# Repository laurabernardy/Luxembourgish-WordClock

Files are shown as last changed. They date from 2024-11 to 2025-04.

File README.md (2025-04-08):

# Lëtzebuergesch Wuertauer - Luxembourgish Word Clock

I taught the excellent [word clock from techniccontroller](https://github.com/techniccontroller/wordclock_esp8266/tree/main) some Luxembourgish.
So this version has a different front plate, grid and an other "start message", as well as the corresponding software changes. The installation process is the same, so I included the authors description in this readme ([down there!](#wordclock-20))

### hardware and its installation

You can find the stl files for the front plate and the letter seperating grid (to avoid light leakage) also in this repo. print it with black PETG (maybe PLA also does the job). Other colors might not keep the light just on one letter.

I followed loosely the [**tutorial**](https://techniccontroller.com/word-clock-with-wifi-and-neopixel/) from techniccontroller when assembling the hardware. 

#### Different and same material 

My wordclock uses 
- as base a 23 cm x 23 cm wooden 3d frame [like this one](https://www.ebay.de/itm/363647167937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)

- diffusion foil (has to be at least frame size) [like this one](https://www.amazon.de/-/en/gp/product/B08R67CGGG/ref=ppx_yo_dt_b_search_asin_title?ie=UTF8&psc=1)

- WS2812B addressable LED stripes 3m, 60 LEDS/m [like this one](https://www.ebay.de/itm/185183965409?var=694400105582)

- and [this](https://www.thingiverse.com/thing:2842012) ESP case on the back

I did not include an on-off-switch in my version and I power it directly from the ESP. If you are unsure with that, you can include the USB socket like in the original tutorial. 
The material, I used same as in the original tutorial were: ESP8266 from AZDelivery, USB power supply 5V/3A,
470 Ohm resistor,
1000uF capacitor,
micro USB cable,
some cables

#### my own assembly

1. I started by 3d printing the Front plate so I could use it, to positionate the LEDs to glue them on the back plate of the frame. For that i used dark eye shadow to trace through the letters on the plate:

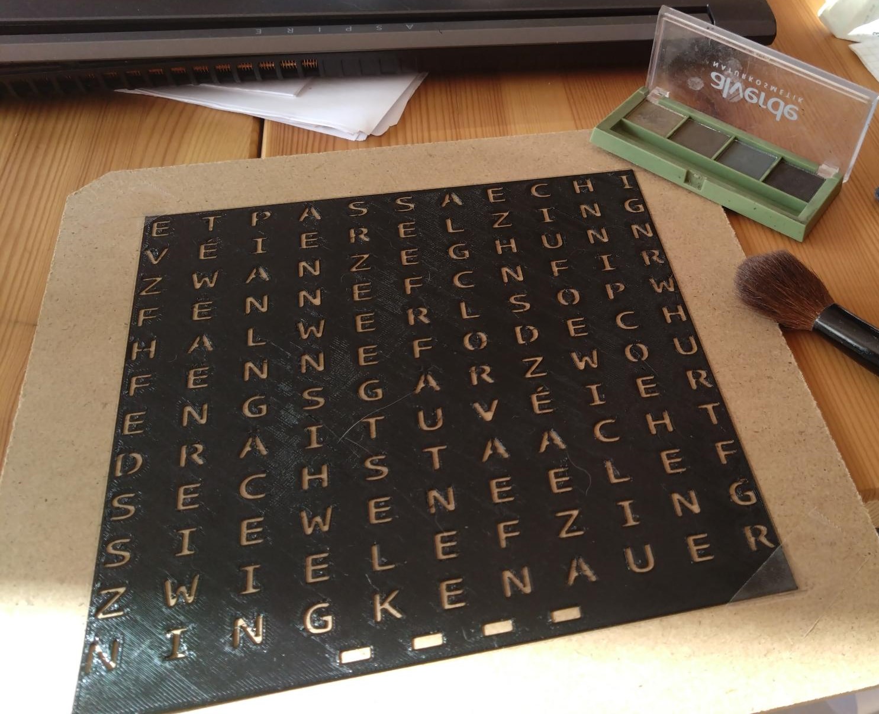
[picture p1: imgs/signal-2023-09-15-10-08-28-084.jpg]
Bild 1
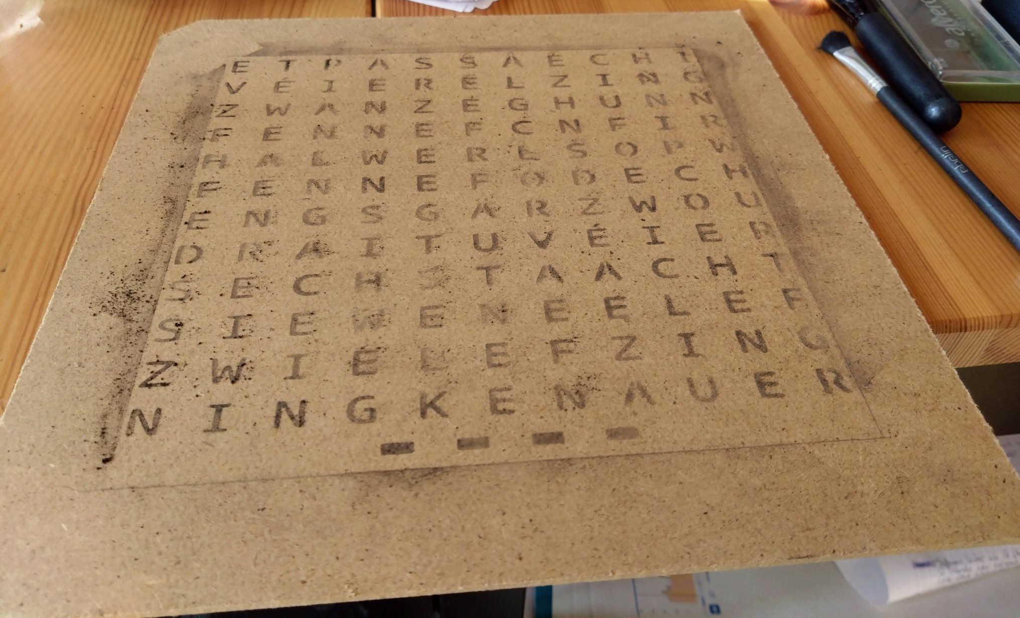
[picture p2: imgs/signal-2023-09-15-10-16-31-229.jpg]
Bild 2
   

3. Then I glued the LEDs strips and connected them following the original tutorial. Keep in mind, that you need 11 LEDs per row and 12 rows (that is different) plus the for LED row at the bottom. 
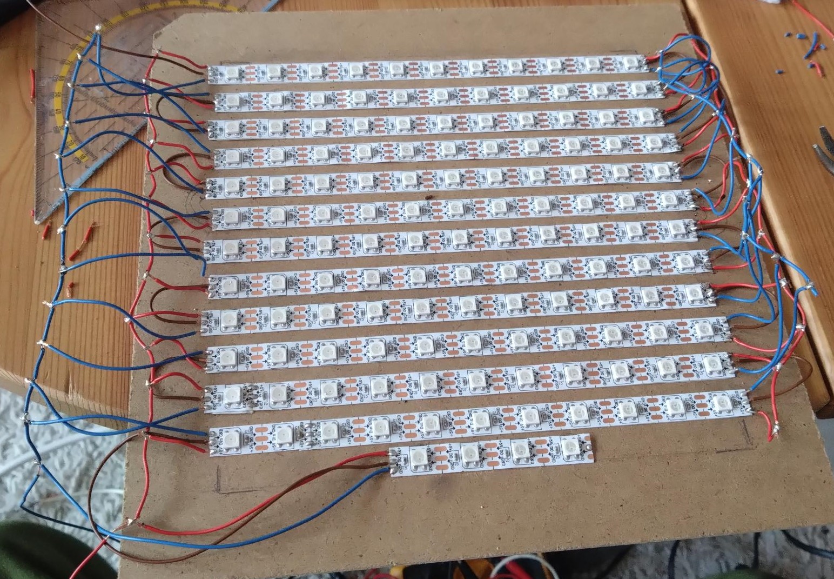
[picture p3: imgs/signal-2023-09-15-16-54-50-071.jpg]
Bild 3
 

4. The connection between the LEDs and to the ESP is also nearly the same as in the original tutorial, I did not include the switch and the additional usb socket. So I connected the LED strips to the VU/5V and the GRD Pin of the ESP.

5. I glued the esp in the printed case from thingiverse at the back of the back plate. 

6. To bring it all together: place the printed grip on the plate, so that every letter is in one of the cells. then you put the diffusor foil on it. Then you put the printed front plate on that. (Ignore the wrong printed grip on top of the image) 
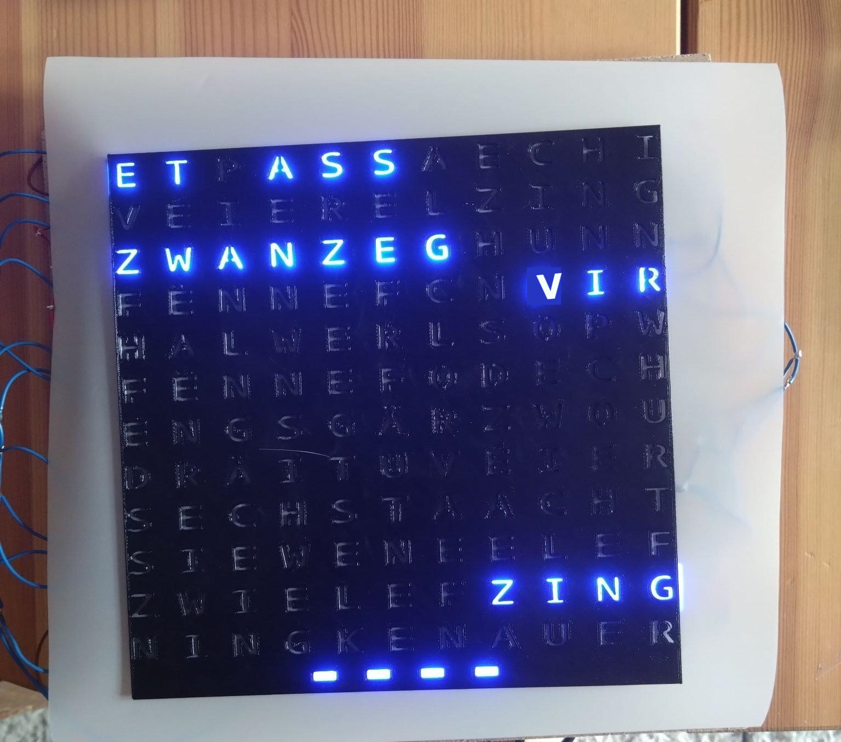
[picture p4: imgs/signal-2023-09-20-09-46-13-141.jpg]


7. You can cut the passepartout of the frame, so it shows all of the letters. Fixate the front plate in the back with some tesa or glue of your gusto. Put it into the frame and - *Taaadaaa* - your Word Clock is ready.

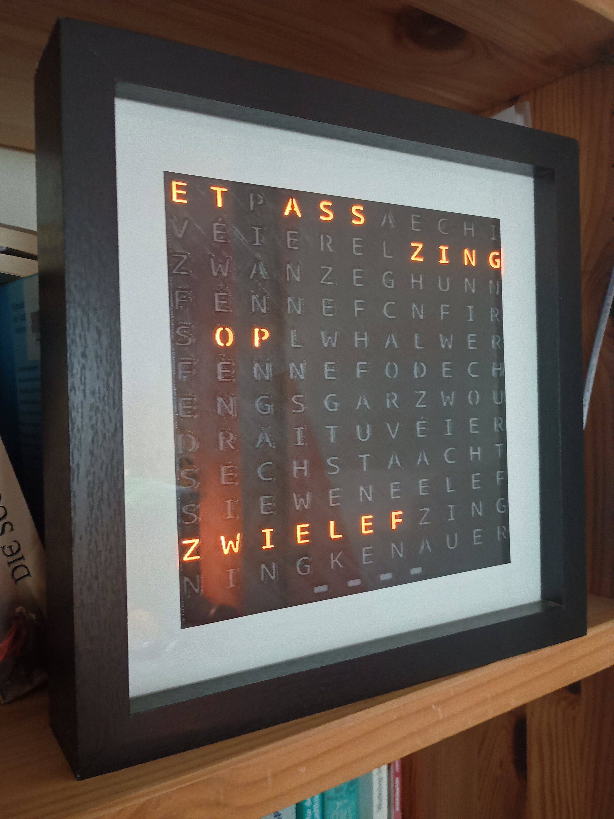
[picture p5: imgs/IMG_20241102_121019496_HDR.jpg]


### small software difference (except the language)

In difference to the original it says "ech hunn dech gär" when starting (it was a present for a beloved one ;-)), you can change that back in wordclock_esp8266.ino, by commenting lines 361 - 379 out and decomment lines 381 - 387. It will show its ip adress instead. 

## Original description from [techniccontroller](https://github.com/techniccontroller/wordclock_esp8266/tree/main)

# Wordclock 2.0

Wordclock 2.0 with ESP8266 and NTP time

More details on my website: https://techniccontroller.com/word-clock-with-wifi-and-neopixel/

**Languages**

The Wordclock is available in **German**, **English** and **Italian** language. By default the language is German. 
To use the English or Italian language please replace the file *wordclockfunctions.ino* with *wordclockfunctions.ino_english* or *wordclockfunctions.ino_italian*.
The code compiles only with one file named *wordclockfunctions.ino*. So please rename the file you want to use to *wordclockfunctions.ino* and replace the existing file.

## Features
- 6 modes (Clock, Digital Clock, SPIRAL animation, TETRIS, SNAKE, PONG)
- time update via NTP server
- automatic summer/wintertime change
- easy WIFI setup with WifiManager
- configurable color
- configurable night mode (start and end time)
- configurable brightness
- automatic mode change
- webserver interface for configuration and control
- physical button to change mode or enable night mode without webserver
- automatic current limiting of LEDs

## Pictures of clock
modes_images2

## Screenshots of webserver UI
screenshots_UI

## Quickstart

1. Clone the project into the sketch folder of the Arduino IDE, 
2. Rename the file "example_secrets.h" to "secrets.h". You don't need to change anything in the file if you want to use the normal WiFi setup with WiFiManager (see section "Remark about the WiFi setup").
3. Install the additional libraries and upload the program to the ESP8266 as usual (See section [*Upload program to ESP8266*](https://github.com/techniccontroller/wordclock_esp8266/blob/main/README.md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) below). 
4. The implemented WiFiManager helps you to set up a WiFi connection with your home WiFi -> on the first startup it will create a WiFi access point named "WordclockAP". Connect your phone to this access point and follow the steps which will be shown to you. 
5. After a successful WiFi setup, open the browser and enter the IP address of your ESP8266 to access the interface of the webserver. 
6. Here you can upload all files located in the folder "data". Please make sure all icons stay in the folder "icons" also on the webserver.

  

## Install needed Libraries

Please download all these libraries as ZIP from GitHub, and extract them in the *libraries* folder of your Sketchbook location (see **File -> Preferences**):

- https://github.com/adafruit/Adafruit-GFX-Library
- https://github.com/adafruit/Adafruit_NeoMatrix
- https://github.com/adafruit/Adafruit_NeoPixel
- https://github.com/tzapu/WiFiManager
- https://github.com/adafruit/Adafruit_BusIO

folder structure should look like this:

```
MySketchbookLocation 
│
└───libraries
│   └───Adafruit-GFX-Library
│   └───Adafruit_NeoMatrix
│   └───Adafruit_NeoPixel
│   └───WiFiManager
│   └───Adafruit_BusIO
│   
└───wordclock_esp8266
    │   wordclock_esp8266.ino
    │   (...)
    |
    └───data
        │   index.html
        |   (...)
        |
        └───icons 
```

## Upload program to ESP8266 with Arduino IDE

#### STEP1: Installation of Arduino IDE
First, the latest version of the Arduino IDE needs to be downloaded and installed from here.

#### STEP2: Installation of ESP8266 Arduino Core
To program the ESP8266 with the Arduino IDE, you need to install the board information first in Arduino IDE. To do that follow the following instructions:

- Start Arduino and open the File -> Preferences window.

- Enter http://arduino.esp8266.com/stable/package_esp8266com_index.json into the Additional Board Manager URLs field. You can add multiple URLs, separating them with commas.


- Open Boards Manager from Tools > Board menu and search for "esp8266".

- Click the install button.

- Don’t forget to select your ESP8266 board from Tools > Board menu after installation (e.g NodeMCU 1.0)


#### STEP3: Upload a program to ESP8266

- Open wordclock_esp8266.ino in Arduino IDE
- Connect ESP8266 board with Computer
- Select right serial Port in Tools -> Port
- Click on the upload button in the Arduino IDE to upload the program to the ESP8266 Module.     


## Remark about the WiFi setup

Regarding the WiFi setting, I have actually implemented two variants: 
1. By default the WifiManager is activated. That is, the word clock makes the first time its own WiFi (should be called "WordclockAP"). There you connect from a cell phone to `192.168.4.1`* and you can perform the configuration of the WiFi settings conveniently as with a SmartHome devices (Very elegant 😊)
2. Another (traditional) variant is to define the wifi credentials in the code (in secrets.h). 
    - For this you have to comment out lines 230 to 251 in the code of the file *wordclock_esp8266.ino* (add /\* before and \*/ after) 
    - and comment out lines 257 to 305 (remove /\* and \*/)
(* default IP provided by the WifiMAnager library.)

## Resetting the WiFi configuration

You can clear the stored WiFi credentials and restart the WiFi setup described above with these steps:
1. Open the settings panel in the web UI.
2. Enable 'Reset WiFi' slider.
3. Save settings.
4. LED test should be performed.
5. Disconnect and reconnect the power. WiFi credentials were removed. The setup should be restarted.
Resetting the wifi credentials does not delete uploaded files.

## Remark about Logging

The wordclock sends continuous log messages to the serial port and via multicast UDP. If you want to see these messages, you have to 

- open the serial monitor in the Arduino IDE (Tools -> Serial Monitor). The serial monitor must be set to 115200 baud.

OR

- run the following steps for the multicast UDP logging:

1. Starting situation: wordclock is connected to WLAN, a computer with installed Python (https://www.python.org/downloads/) is in the same local area network (WLAN or LAN doesn't matter).
3. Open the file **multicastUDP_receiver.py** in a text editor and in line 81 enter the IP address of the computer (not the wordclock!).
```python	
# ip address of network interface
MCAST_IF_IP = '192.168.0.7'
```
4. Execute the script with following command: 

```bash
python multicastUDP_receiver_analyzer.py
```

5. Now you should see the log messages of the word clock (every 5 seconds a heartbeat message and the currently displayed time). 
If this is not the case, there could be a problem with the network settings of the computer, then recording is unfortunately not possible.

6. If special events (failed NTP update, reboot) occur, a section of the log is saved in a file called *log.txt*. 
In principle, the events are not critical and will occur from time to time, but should not be too frequent.

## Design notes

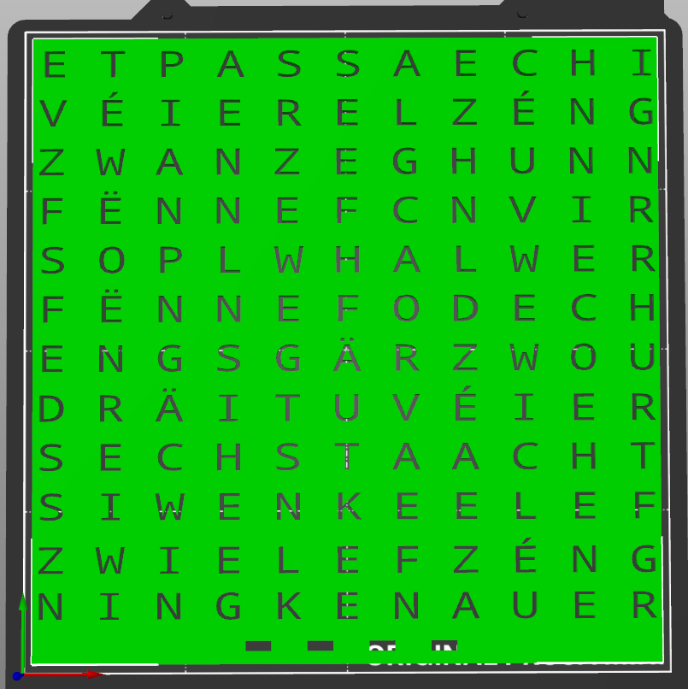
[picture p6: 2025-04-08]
grid/corrected_frontplate.png

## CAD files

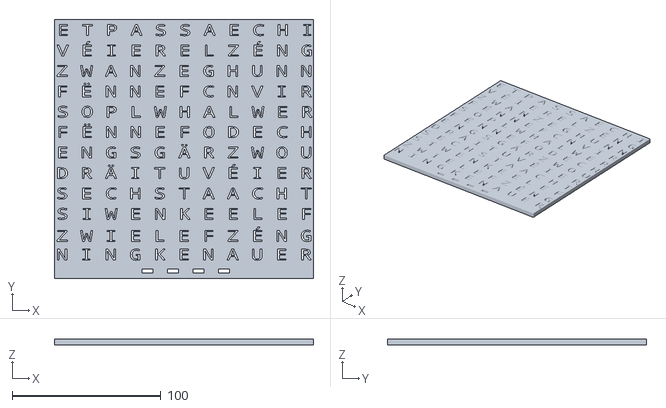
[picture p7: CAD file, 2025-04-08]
grid/corrected_wuertauer.stl
174.4 x 174.4 x 4.00

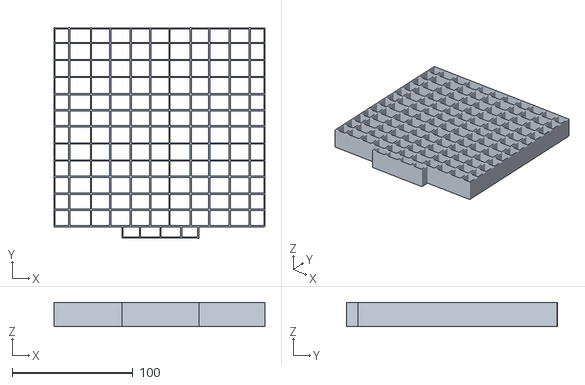
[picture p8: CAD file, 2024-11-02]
grid/Grid.stl
174.8 x 174.4 x 20.0

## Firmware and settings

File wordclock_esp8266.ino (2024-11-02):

/**
 * Wordclock 2.0 - Wordclock with ESP8266 and NTP time update
 * 
 * created by techniccontroller 04.12.2021
 * 
 * components:
 * - ESP8266
 * - Neopixelstrip
 * 
 * Board settings:
 * - Board: NodeMCU 1.0 (ESP-12E Module)
 * - Flash Size: 4MB (FS:2MB OTA:~1019KB)
 * - Upload Speed: 115200
 *  
 * 
 * with code parts from:
 * - Adafruit NeoPixel strandtest.ino, https://github.com/adafruit/Adafruit_NeoPixel/blob/master/examples/strandtest/strandtest.ino
 * - Esp8266 und Esp32 webserver https://fipsok.de/
 * - https://github.com/pmerlin/PMR-LED-Table/blob/master/tetrisGame.ino
 * - https://randomnerdtutorials.com/wifimanager-with-esp8266-autoconnect-custom-parameter-and-manage-your-ssid-and-password/ 
 * 
 */

#include "secrets.h"                    // rename the file example_secrets.h to secrets.h after cloning the project. More information in README.md
#include <LittleFS.h>
#include <Adafruit_GFX.h>               // https://github.com/adafruit/Adafruit-GFX-Library
#include <Adafruit_NeoMatrix.h>         // https://github.com/adafruit/Adafruit_NeoMatrix
#include <Adafruit_NeoPixel.h>          // NeoPixel library used to run the NeoPixel LEDs: https://github.com/adafruit/Adafruit_NeoPixel
#include <ESP8266WiFi.h>
#include <WiFiUdp.h>
#include <ArduinoOTA.h>
#include <ESP8266WebServer.h>
#include "Base64.h"                    // copied from https://github.com/Xander-Electronics/Base64 
#include <DNSServer.h>
#include <WiFiManager.h>                //https://github.com/tzapu/WiFiManager WiFi Configuration Magic
#include <EEPROM.h>                     //from ESP8266 Arduino Core (automatically installed when ESP8266 was installed via Boardmanager)

// own libraries
#include "udplogger.h"
#include "ntp_client_plus.h"
#include "ledmatrix.h"
#include "tetris.h"
#include "snake.h"
#include "pong.h"


// ----------------------------------------------------------------------------------
//                                        CONSTANTS
// ----------------------------------------------------------------------------------

#define EEPROM_SIZE 30      // size of EEPROM to save persistent variables
#define ADR_NM_START_H 0
#define ADR_NM_END_H 4
#define ADR_NM_START_M 8
#define ADR_NM_END_M 12
#define ADR_BRIGHTNESS 16
#define ADR_MC_RED 20
#define ADR_MC_GREEN 22
#define ADR_MC_BLUE 24


#define NEOPIXELPIN 5       // pin to which the NeoPixels are attached
#define NUMPIXELS 125       // number of pixels attached to Attiny85
#define BUTTONPIN 14        // pin to which the button is attached
#define LEFT 1
#define RIGHT 2
#define LINE 10
#define RECT 5

#define PERIOD_HEARTBEAT 1000
#define PERIOD_ANIMATION 200
#define PERIOD_TETRIS 50
#define PERIOD_SNAKE 50
#define PERIOD_PONG 10
#define TIMEOUT_LEDDIRECT 5000
#define PERIOD_STATECHANGE 10000
#define PERIOD_NTPUPDATE 30000
#define PERIOD_TIMEVISUUPDATE 1000
#define PERIOD_MATRIXUPDATE 100
#define PERIOD_NIGHTMODECHECK 20000

#define SHORTPRESS 100
#define LONGPRESS 2000

#define CURRENT_LIMIT_LED 2500 // limit the total current sonsumed by LEDs (mA)

#define DEFAULT_SMOOTHING_FACTOR 0.5

// number of colors in colors array
#define NUM_COLORS 7

// own datatype for matrix movement (snake and spiral)
enum direction {right, left, up, down};

// width of the led matrix
#define WIDTH 11
// height of the led matrix
#define HEIGHT 12

// own datatype for state machine states
#define NUM_STATES 6
enum ClockState {st_clock, st_diclock, st_spiral, st_tetris, st_snake, st_pingpong};
const String stateNames[] = {"Clock", "DiClock", "Sprial", "Tetris", "Snake", "PingPong"};
// PERIODS for each state (different for stateAutoChange or Manual mode)
const uint16_t PERIODS[2][NUM_STATES] = { { PERIOD_TIMEVISUUPDATE, // stateAutoChange = 0
                                            PERIOD_TIMEVISUUPDATE, 
                                            PERIOD_ANIMATION,
                                            PERIOD_TETRIS, 
                                            PERIOD_SNAKE,  
                                            PERIOD_PONG},
                                          { PERIOD_TIMEVISUUPDATE, // stateAutoChange = 1
                                            PERIOD_TIMEVISUUPDATE, 
                                            PERIOD_ANIMATION,
                                            PERIOD_ANIMATION, 
                                            PERIOD_ANIMATION,  
                                            PERIOD_PONG}};

// ports
const unsigned int localPort = 2390;
const unsigned int HTTPPort = 80;
const unsigned int logMulticastPort = 8123;
const unsigned int DNSPort = 53;

// ip addresses for multicast logging
IPAddress logMulticastIP = IPAddress(230, 120, 10, 2);

// ip addresses for Access Point
IPAddress IPAdress_AccessPoint(192,168,10,2);
IPAddress Gateway_AccessPoint(192,168,10,0);
IPAddress Subnetmask_AccessPoint(255,255,255,0);

// hostname
const String hostname = "wordclock";

// URL DNS server
const char WebserverURL[] = "www.wordclock.local";

// ----------------------------------------------------------------------------------
//                                        GLOBAL VARIABLES
// ----------------------------------------------------------------------------------

// Webserver
ESP8266WebServer server(HTTPPort);

//DNS Server
DNSServer DnsServer;

// Wifi server. keep around to support resetting.
WiFiManager wifiManager;

// When we setup the NeoPixel library, we tell it how many pixels, and which pin to use to send signals.
// Note that for older NeoPixel strips you might need to change the third parameter--see the strandtest
// example for more information on possible values.
Adafruit_NeoMatrix matrix = Adafruit_NeoMatrix(WIDTH, HEIGHT+1, NEOPIXELPIN,
  NEO_MATRIX_TOP + NEO_MATRIX_LEFT +
  NEO_MATRIX_ROWS + NEO_MATRIX_ZIGZAG,
  NEO_GRB            + NEO_KHZ800);


// seven predefined colors24bit (green, red, yellow, purple, orange, lightgreen, blue) 
const uint32_t colors24bit[NUM_COLORS] = {
  LEDMatrix::Color24bit(0, 255, 0),
  LEDMatrix::Color24bit(255, 0, 0),
  LEDMatrix::Color24bit(200, 200, 0),
  LEDMatrix::Color24bit(255, 0, 200),
  LEDMatrix::Color24bit(255, 128, 0), 
  LEDMatrix::Color24bit(0, 128, 0), 
  LEDMatrix::Color24bit(0, 0, 255) };

uint8_t brightness = 40;            // current brightness of leds
bool sprialDir = false;

// timestamp variables
long lastheartbeat = millis();      // time of last heartbeat sending
long lastStep = millis();           // time of last animation step
long lastLEDdirect = 0;             // time of last direct LED command (=> fall back to normal mode after timeout)
long lastStateChange = millis();    // time of last state change
long lastNTPUpdate = millis() - (PERIOD_NTPUPDATE-5000);  // time of last NTP update
long lastAnimationStep = millis();  // time of last Matrix update
long lastNightmodeCheck = millis(); // time of last nightmode check
long buttonPressStart = 0;          // time of push button press start 

// Create necessary global objects
UDPLogger logger;
WiFiUDP NTPUDP;
NTPClientPlus ntp = NTPClientPlus(NTPUDP, "pool.ntp.org", 1, true);
LEDMatrix ledmatrix = LEDMatrix(&matrix, brightness, &logger);
Tetris mytetris = Tetris(&ledmatrix, &logger);
Snake mysnake = Snake(&ledmatrix, &logger);
Pong mypong = Pong(&ledmatrix, &logger);

float filterFactor = DEFAULT_SMOOTHING_FACTOR;// stores smoothing factor for led transition
uint8_t currentState = st_clock;              // stores current state
bool stateAutoChange = false;                 // stores state of automatic state change
bool nightMode = false;                       // stores state of nightmode
uint32_t maincolor_clock = colors24bit[2];    // color of the clock and digital clock
uint32_t maincolor_snake = colors24bit[1];    // color of the random snake animation
bool apmode = false;                          // stores if WiFi AP mode is active

// nightmode settings
int nightModeStartHour = 22;
int nightModeStartMin = 0;
int nightModeEndHour = 7;
int nightModeEndMin = 0;

// Watchdog counter to trigger restart if NTP update was not possible 30 times in a row (5min)
int watchdogCounter = 30;

// ----------------------------------------------------------------------------------
//                                        SETUP
// ----------------------------------------------------------------------------------

void setup() {
  // put your setup code here, to run once:
  Serial.begin(115200);
  delay(100);
  Serial.println();
  Serial.printf("\nSketchname: %s\nBuild: %s\n", (__FILE__), (__TIMESTAMP__));
  Serial.println();

  //Init EEPROM
  EEPROM.begin(EEPROM_SIZE);

  // Load color for clock from EEPROM
  loadMainColor();

  // configure button pin as input
  pinMode(BUTTONPIN, INPUT_PULLUP);

  // setup Matrix LED functions
  ledmatrix.setupMatrix();
  ledmatrix.setCurrentLimit(CURRENT_LIMIT_LED);

  // Turn on minutes leds (blue)
  ledmatrix.setMinIndicator(15, colors24bit[6]);
  ledmatrix.drawOnMatrixInstant();


  /** Use WiFiMaanger for handling initial Wifi setup **/

  // Local intialization. Once its business is done, there is no need to keep it around


  // Uncomment and run it once, if you want to erase all the stored information
  //wifiManager.resetSettings();

  // set custom ip for portal
  //wifiManager.setAPStaticIPConfig(IPAdress_AccessPoint, Gateway_AccessPoint, Subnetmask_AccessPoint);

  // fetches ssid and pass from eeprom and tries to connect
  // if it does not connect it starts an access point with the specified name
  // here "wordclockAP"
  // and goes into a blocking loop awaiting configuration
  wifiManager.autoConnect(AP_SSID);

  // if you get here you have connected to the WiFi
  Serial.println("Connected.");
  Serial.println("IP address: ");
  Serial.println(WiFi.localIP()); 

  // Turn off minutes leds
  ledmatrix.setMinIndicator(15, 0);
  ledmatrix.drawOnMatrixInstant();

   
  
  /** (alternative) Use directly STA/AP Mode of ESP8266   **/
  
  /* 
  // We start by connecting to a WiFi network
  Serial.print("Connecting to ");
  Serial.println(WIFI_SSID);
  
  // We start by connecting to a WiFi network
  WiFi.mode(WIFI_STA);
  //Set new hostname
  WiFi.hostname(hostname.c_str());
  WiFi.begin(WIFI_SSID, WIFI_PASS);
  //wifi_station_set_hostname("esplamp");

  int timeoutcounter = 0;
  while (WiFi.status() != WL_CONNECTED && timeoutcounter < 30) {
    ledmatrix.setMinIndicator(15, colors24bit[6]);
    ledmatrix.drawOnMatrixInstant();
    delay(250);
    ledmatrix.setMinIndicator(15, 0);
    ledmatrix.drawOnMatrixInstant();
    delay(250);
    Serial.print(".");
    timeoutcounter++;
  }

  // start request of program
  if (WiFi.status() == WL_CONNECTED) {      //Check WiFi connection status
    Serial.println("");

    Serial.println("WiFi connected");
    Serial.println("IP address: ");
    Serial.println(WiFi.localIP()); 
    WiFi.setAutoReconnect(true);
    WiFi.persistent(true);
  
  } else {
    // no wifi found -> open access point
    WiFi.mode(WIFI_AP);
    WiFi.softAPConfig(IPAdress_AccessPoint, Gateway_AccessPoint, Subnetmask_AccessPoint);
    WiFi.softAP(AP_SSID, AP_PASS);
    apmode = true;

    // start DNS Server
    DnsServer.setTTL(300);
    DnsServer.start(DNSPort, WebserverURL, IPAdress_AccessPoint);

    IPAddress myIP = WiFi.softAPIP();
    Serial.print("AP IP address: ");
    Serial.println(myIP);
  }*/

  // init ESP8266 File manager (LittleFS)
  setupFS();

  // setup OTA
  setupOTA(hostname);

  server.on("/cmd", handleCommand); // process commands
  server.on("/data", handleDataRequest); // process datarequests
  server.on("/leddirect", HTTP_POST, handleLEDDirect); // Call the 'handleLEDDirect' function when a POST request is made to URI "/leddirect"
  server.begin();
  
  // create UDP Logger to send logging messages via UDP multicast
  logger = UDPLogger(WiFi.localIP(), logMulticastIP, logMulticastPort);
  logger.setName("Wordclock 2.0");
  logger.logString("Start program\n");
  delay(10);
  logger.logString("Sketchname: "+ String(__FILE__));
  delay(10);
  logger.logString("Build: " + String(__TIMESTAMP__));
  delay(10);
  logger.logString("IP: " + WiFi.localIP().toString());
  delay(10);
  logger.logString("Reset Reason: " + ESP.getResetReason());

  if(!ESP.getResetReason().equals("Software/System restart")){
    // test quickly each LED
    for(int r = 0; r < HEIGHT; r++){
        for(int c = 0; c < WIDTH; c++){
        matrix.fillScreen(0);
        matrix.drawPixel(c, r, LEDMatrix::color24to16bit(colors24bit[2]));
        matrix.show();
        delay(10); 
        }
    }
    
    // clear Matrix
    matrix.fillScreen(0);
    matrix.show();
    delay(200);

    // display IP
    uint8_t address = WiFi.localIP()[3];
    matrix.drawPixel(7, 0, LEDMatrix::color24to16bit(colors24bit[4]));
    matrix.drawPixel(8, 0, LEDMatrix::color24to16bit(colors24bit[4]));
    matrix.drawPixel(9, 0, LEDMatrix::color24to16bit(colors24bit[4]));
    matrix.drawPixel(7, 2, LEDMatrix::color24to16bit(colors24bit[4]));
    matrix.drawPixel(8, 2, LEDMatrix::color24to16bit(colors24bit[4]));
    matrix.drawPixel(9, 2, LEDMatrix::color24to16bit(colors24bit[4]));
    matrix.drawPixel(10, 2, LEDMatrix::color24to16bit(colors24bit[4]));
    matrix.drawPixel(7, 5, LEDMatrix::color24to16bit(colors24bit[4]));
    matrix.drawPixel(8, 5, LEDMatrix::color24to16bit(colors24bit[4]));
    matrix.drawPixel(9, 5, LEDMatrix::color24to16bit(colors24bit[4]));
    matrix.drawPixel(10, 5, LEDMatrix::color24to16bit(colors24bit[4]));
    matrix.drawPixel(4, 6, LEDMatrix::color24to16bit(colors24bit[4]));
    matrix.drawPixel(5, 6, LEDMatrix::color24to16bit(colors24bit[4]));
    matrix.drawPixel(6, 6, LEDMatrix::color24to16bit(colors24bit[4]));
    matrix.show();
    delay(8000);
    matrix.fillScreen(0);
    matrix.show();
    delay(200);

    //ledmatrix.printChar(1, 0, 'I', maincolor_clock);
    //ledmatrix.printChar(5, 0, 'P', maincolor_clock);
    //ledmatrix.printNumber(0, 6, (address/100), maincolor_clock);
    //ledmatrix.printNumber(4, 6, (address/10)%10, maincolor_clock);
    //ledmatrix.printNumber(8, 6, address%10, maincolor_clock);
    //ledmatrix.drawOnMatrixInstant();
    //delay(2000);


    // clear matrix
    ledmatrix.gridFlush();
    ledmatrix.drawOnMatrixInstant();
  }

  // setup NTP
  ntp.setupNTPClient();
  logger.logString("NTP running");
  logger.logString("Time: " +  ntp.getFormattedTime());
  logger.logString("TimeOffset (seconds): " + String(ntp.getTimeOffset()));

  // show the current time for short time in words
  int hours = ntp.getHours24();
  int minutes = ntp.getMinutes();
  String timeMessage = timeToString(hours, minutes);
  showStringOnClock(timeMessage, maincolor_clock);
  drawMinuteIndicator(minutes, maincolor_clock);
  ledmatrix.drawOnMatrixSmooth(filterFactor);


  // init all animation modes
  // init snake
  randomsnake(true, 8, colors24bit[1], -1);
  // init spiral
  spiral(true, sprialDir, WIDTH-6);
  // init random tetris
  randomtetris(true);

  // Read nightmode setting from EEPROM
  nightModeStartHour = readIntEEPROM(ADR_NM_START_H);
  nightModeStartMin = readIntEEPROM(ADR_NM_START_M);
  nightModeEndHour = readIntEEPROM(ADR_NM_END_H);
  nightModeEndMin = readIntEEPROM(ADR_NM_END_M);
  if(nightModeStartHour < 0 || nightModeStartHour > 23) nightModeStartHour = 22;
  if(nightModeStartMin < 0 || nightModeStartMin > 59) nightModeStartMin = 0;
  if(nightModeEndHour < 0 || nightModeEndHour > 23) nightModeEndHour = 7;
  if(nightModeEndMin < 0 || nightModeEndMin > 59) nightModeEndMin = 0;
  logger.logString("Nightmode starts at: " + String(nightModeStartHour) + ":" + String(nightModeStartMin));
  logger.logString("Nightmode ends at: " + String(nightModeEndHour) + ":" + String(nightModeEndMin));

  // Read brightness setting from EEPROM, lower limit is 10 so that the LEDs are not completely off
  brightness = readIntEEPROM(ADR_BRIGHTNESS);
  if(brightness < 10) brightness = 10;
  logger.logString("Brightness: " + String(brightness));
  ledmatrix.setBrightness(brightness);
  
}


// ----------------------------------------------------------------------------------
//                                        LOOP
// ----------------------------------------------------------------------------------

void loop() {
  // handle OTA
  handleOTA();
  
  // handle Webserver
  server.handleClient();

  // send regularly heartbeat messages via UDP multicast
  if(millis() - lastheartbeat > PERIOD_HEARTBEAT){
    logger.logString("Heartbeat, state: " + stateNames[currentState] + ", FreeHeap: " + ESP.getFreeHeap() + ", HeapFrag: " + ESP.getHeapFragmentation() + ", MaxFreeBlock: " + ESP.getMaxFreeBlockSize() + "\n");
    lastheartbeat = millis();

    // Check wifi status (only if no apmode)
    if(!apmode && WiFi.status() != WL_CONNECTED){
      Serial.println("connection lost");
      ledmatrix.gridAddPixel(0, 5, colors24bit[1]);
      ledmatrix.drawOnMatrixInstant();
    }
  }

  // handle mode behaviours (trigger loopCycles of different modes depending on current mode)
  if(!nightMode && (millis() - lastStep > PERIODS[stateAutoChange][currentState]) && (millis() - lastLEDdirect > TIMEOUT_LEDDIRECT)){
    switch(currentState){
      // state clock
      case st_clock:
        {
          int hours = ntp.getHours24();
          int minutes = ntp.getMinutes();
          showStringOnClock(timeToString(hours, minutes), maincolor_clock);
          drawMinuteIndicator(minutes, maincolor_clock);
        }
        break;
      // state diclock
      case st_diclock:
        {
          int hours = ntp.getHours24();
          int minutes = ntp.getMinutes();
          showDigitalClock(hours, minutes, maincolor_clock);
        }
        break;
      // state spiral
      case st_spiral:
        {
          int res = spiral(false, sprialDir, WIDTH-6);
          if(res && sprialDir == 0){
            // change spiral direction to closing (draw empty leds)
            sprialDir = 1;
            // init spiral with new spiral direction
            spiral(true, sprialDir, WIDTH-6);
            
          }else if(res && sprialDir == 1){
            // reset spiral direction to normal drawing leds
            sprialDir = 0;
            // init spiral with new spiral direction
            spiral(true, sprialDir, WIDTH-6);
          }
        }
        break;
      // state tetris
      case st_tetris:
        {
          if(stateAutoChange){
            randomtetris(false);
          }
          else{
            mytetris.loopCycle();
          }
        }
        break;
      // state snake
      case st_snake:
        {
          if(stateAutoChange){
            ledmatrix.gridFlush();
            int res = randomsnake(false, 8, maincolor_snake, -1);
            if(res){
              // init snake for next run
              randomsnake(true, 8, maincolor_snake, -1);
            }
          }
          else{
            mysnake.loopCycle();
          }
        }
        break;
      // state pingpong
      case st_pingpong:
        {
          mypong.loopCycle();
        }
        break;
    }    
    
    lastStep = millis();
  }

  // periodically write colors to matrix
  if(millis() - lastAnimationStep > PERIOD_MATRIXUPDATE){
    ledmatrix.drawOnMatrixSmooth(filterFactor);
    lastAnimationStep = millis();
  }

  // handle button press
  handleButton();

  // handle state changes
  if(stateAutoChange && (millis() - lastStateChange > PERIOD_STATECHANGE) && !nightMode){
    // increment state variable and trigger state change
    stateChange((currentState + 1) % NUM_STATES);
    
    // save last automatic state change
    lastStateChange = millis();
  }

  // NTP time update
  if(millis() - lastNTPUpdate > PERIOD_NTPUPDATE){
    int res = ntp.updateNTP();
    if(res == 0){
      ntp.calcDate();
      logger.logString("NTP-Update successful");
      logger.logString("Time: " +  ntp.getFormattedTime());
      logger.logString("Date: " +  ntp.getFormattedDate());
      logger.logString("Day of Week (Mon=1, Sun=7): " +  String(ntp.getDayOfWeek()));
      logger.logString("TimeOffset (seconds): " + String(ntp.getTimeOffset()));
      logger.logString("Summertime: " + String(ntp.updateSWChange()));
      lastNTPUpdate = millis();
      watchdogCounter = 30;
    }
    else if(res == -1){
      logger.logString("NTP-Update not successful. Reason: Timeout");
      lastNTPUpdate += 10000;
      watchdogCounter--;
    }
    else if(res == 1){
      logger.logString("NTP-Update not successful. Reason: Too large time difference");
      logger.logString("Time: " +  ntp.getFormattedTime());
      logger.logString("Date: " +  ntp.getFormattedDate());
      logger.logString("Day of Week (Mon=1, Sun=7): " +  ntp.getDayOfWeek());
      logger.logString("TimeOffset (seconds): " + String(ntp.getTimeOffset()));
      logger.logString("Summertime: " + String(ntp.updateSWChange()));
      lastNTPUpdate += 10000;
      watchdogCounter--;
    }
    else {
      logger.logString("NTP-Update not successful. Reason: NTP time not valid (<1970)");
      lastNTPUpdate += 10000;
      watchdogCounter--;
    }

    logger.logString("Watchdog Counter: " + String(watchdogCounter));
    if(watchdogCounter <= 0){
        logger.logString("Trigger restart due to watchdog...");
        delay(100);
        ESP.restart();
    }
    
  }

  // check if nightmode need to be activated
  if(millis() - lastNightmodeCheck > PERIOD_NIGHTMODECHECK){
    int hours = ntp.getHours24();
    int minutes = ntp.getMinutes();
    
    if(hours == nightModeStartHour && minutes == nightModeStartMin){
      setNightmode(true);
    }
    else if(hours == nightModeEndHour && minutes == nightModeEndMin){
      setNightmode(false);
    }
    
    lastNightmodeCheck = millis();
  }
 
}


// ----------------------------------------------------------------------------------
//                                        OTHER FUNCTIONS
// ----------------------------------------------------------------------------------
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

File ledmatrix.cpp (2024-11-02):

#include "ledmatrix.h"
#include "own_font.h"

/**
 * @brief Construct a new LEDMatrix::LEDMatrix object
 * 
 * @param mymatrix pointer to Adafruit_NeoMatrix object
 * @param mybrightness the initial brightness of the leds
 * @param mylogger pointer to the UDPLogger object
 */
LEDMatrix::LEDMatrix(Adafruit_NeoMatrix *mymatrix, uint8_t mybrightness, UDPLogger *mylogger){
    neomatrix = mymatrix;
    brightness = mybrightness;
    logger = mylogger;
    currentLimit = DEFAULT_CURRENT_LIMIT;
}

/**
 * @brief Convert RGB value to 24bit color value
 * 
 * @param r red value (0-255)
 * @param g green value (0-255)
 * @param b blue value (0-255)
 * @return uint32_t 24bit color value
 */
uint32_t LEDMatrix::Color24bit(uint8_t r, uint8_t g, uint8_t b) 
{
  return ((uint32_t)r << 16) | ((uint32_t)g <<  8) | b;
}

/**
 * @brief Convert 24bit color to 16bit color
 * 
 * @param color24bit 24bit color value
 * @return uint16_t 16bit color value
 */
uint16_t LEDMatrix::color24to16bit(uint32_t color24bit){
  uint8_t r = color24bit >> 16 & 0xff;
  uint8_t g = color24bit >> 8 & 0xff;
  uint8_t b = color24bit & 0xff;
  return ((uint16_t)(r & 0xF8) << 8) |
         ((uint16_t)(g & 0xFC) << 3) |
                    (b         >> 3);
}

/**
 * @brief Input a value 0 to 255 to get a color value. The colors are a transition r - g - b - back to r.
 * 
 * @param WheelPos Value between 0 and 255
 * @return uint32_t return 24bit color of colorwheel
 */
uint32_t LEDMatrix::Wheel(uint8_t WheelPos)
{
    WheelPos = 255 - WheelPos;
    if (WheelPos < 85)
    {
        return Color24bit(255 - WheelPos * 3, 0, WheelPos * 3);
    }
    if (WheelPos < 170)
    {
        WheelPos -= 85;
        return Color24bit(0, WheelPos * 3, 255 - WheelPos * 3);
    }
    WheelPos -= 170;
    return Color24bit(WheelPos * 3, 255 - WheelPos * 3, 0);
}

/**
 * @brief Interpolates two colors24bit and returns an color of the result
 * 
 * @param color1 startcolor for interpolation
 * @param color2 endcolor for interpolatio
 * @param factor which color is wanted on the path from start to end color
 * @return uint32_t interpolated color
 */
uint32_t LEDMatrix::interpolateColor24bit(uint32_t color1, uint32_t color2, float factor)
{
    uint8_t resultRed = color1 >> 16 & 0xff;
    uint8_t resultGreen = color1 >> 8 & 0xff;
    uint8_t resultBlue = color1 & 0xff;
    resultRed = (uint8_t)(resultRed + (int16_t)(factor * ((int16_t)(color2 >> 16 & 0xff) - (int16_t)resultRed)));
    resultGreen = (uint8_t)(resultGreen + (int16_t)(factor * ((int16_t)(color2 >> 8 & 0xff) - (int16_t)resultGreen)));
    resultBlue = (uint8_t)(resultBlue + (int16_t)(factor * ((int16_t)(color2 & 0xff) - (int16_t)resultBlue)));
    return Color24bit(resultRed, resultGreen, resultBlue);
}

/**
 * @brief Setup function for LED matrix
 * 
 */
void LEDMatrix::setupMatrix() 
{
    (*neomatrix).begin();       
    (*neomatrix).setTextWrap(false);
    (*neomatrix).setBrightness(brightness);
    randomSeed(analogRead(0));
}

/**
 * @brief Turn on the minutes indicator leds with the provided pattern (binary encoded)
 * 
 * @param pattern the binary encoded pattern of the minute indicator
 * @param color color to be displayed
 */
void LEDMatrix::setMinIndicator(uint8_t pattern, uint32_t color)
{
  // pattern:
  // 15 -> 1111
  // 14 -> 1110
  // (...)
  //  2 -> 0010
  //  1 -> 0001
  //  0 -> 0000
  if(pattern & 1){
    targetindicators[3] = color;
  }
  if(pattern >> 1 & 1){
    targetindicators[2] = color;
  }
  if(pattern >> 2 & 1){
    targetindicators[1] = color;
  }
  if(pattern >> 3 & 1){
    targetindicators[0] = color;
  }
}

/**
 * @brief "Activates" a pixel in targetgrid with color
 * 
 * @param x x-position of pixel
 * @param y y-position of pixel
 * @param color color of pixel
 */
void LEDMatrix::gridAddPixel(uint8_t x, uint8_t y, uint32_t color)
{
  // limit ranges of x and y
  if(x >= 0 && x < WIDTH && y >= 0 && y < HEIGHT){
    targetgrid[y][x] = color;
  }
  else{
    //logger->logString("Index out of Range: " + String(x) + ", " + String(y));
  }
}

/**
 * @brief "Deactivates" all pixels in targetgrid
 * 
 */
void LEDMatrix::gridFlush(void)
{
    // set a zero to each pixel
    for(uint8_t i=0; i<HEIGHT; i++){
        for(uint8_t j=0; j<WIDTH; j++){
            targetgrid[i][j] = 0;
        }
    }
    // set every minutes indicator led to 0
    targetindicators[0] = 0;
    targetindicators[1] = 0;
    targetindicators[2] = 0;
    targetindicators[3] = 0;
}

/**
 * @brief Write target pixels directly to leds
 * 
 */
void LEDMatrix::drawOnMatrixInstant(){
  drawOnMatrix(1.0);
}

/**
 * @brief Write target pixels with low pass filter to leds
 * 
 * @param factor factor between 0 and 1 (1.0 = hard, 0.1 = smooth)
 */
void LEDMatrix::drawOnMatrixSmooth(float factor){
  drawOnMatrix(factor);
}

/**
 * @brief Draws the targetgrid to the ledmatrix
 * 
 * @param factor factor between 0 and 1 (1.0 = hard, 0.1 = smooth)
 */
void LEDMatrix::drawOnMatrix(float factor){
  uint16_t totalCurrent = 0;
  // loop over all leds in matrix
  for(int s = 0; s < WIDTH; s++){
    for(int z = 0; z < HEIGHT; z++){
      // inplement momentum as smooth transistion function
      uint32_t filteredColor = interpolateColor24bit(currentgrid[z][s], targetgrid[z][s], factor);
      (*neomatrix).drawPixel(s, z, color24to16bit(filteredColor)); 
      currentgrid[z][s] = filteredColor;
      totalCurrent += calcEstimatedLEDCurrent(filteredColor);
    } 
  }

  // loop over all minute indicator leds
  for(int i = 0; i < 4; i++){
    uint32_t filteredColor = interpolateColor24bit(currentindicators[i], targetindicators[i], factor);
    (*neomatrix).drawPixel(i, HEIGHT, color24to16bit(filteredColor));
    currentindicators[i] = filteredColor;
    totalCurrent += calcEstimatedLEDCurrent(filteredColor);
  }

  // Check if totalCurrent reaches CURRENTLIMIT -> if yes reduce brightness
  if(totalCurrent > currentLimit){
    uint8_t newBrightness = brightness * float(currentLimit)/float(totalCurrent);
    //logger->logString("CurrentLimit reached!!!: " + String(totalCurrent) + ", new: " + String(newBrightness));
    (*neomatrix).setBrightness(newBrightness);
  }
  (*neomatrix).show();
}

/**
 * @brief Shows a 1-digit number on LED matrix (5x3)
 * 
 * @param xpos x of left top corner of digit
 * @param ypos y of left top corner of digit
 * @param number number to display
 * @param color color to display (24bit)
 */
void LEDMatrix::printNumber(uint8_t xpos, uint8_t ypos, uint8_t number, uint32_t color)
{
  for(int y=ypos, i = 0; y < (ypos+5); y++, i++){
    for(int x=xpos, k = 2; x < (xpos+3); x++, k--){
      if((numbers_font[number][i] >> k) & 0x1){
        gridAddPixel(x, y, color);
      }
    }
  }
}
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

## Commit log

2023-09-04 fix 24bit color reference
    [wordclock_esp8266.ino]
2024-11-02 Luxembourgisation of the word clock
    [Grid.stl, Wuertauer.stl, grid_wordclock2.0_20x20cm.stl]
2025-04-08 now the luxembourgish is also LOD conform
    Zing --> Zéng
    Fir --> Vir
    [Wuertauer.stl, corrected_wuertauer.stl]
2025-04-08 more corrected Luxembourgish
    [corrected_wuertauer.stl]
